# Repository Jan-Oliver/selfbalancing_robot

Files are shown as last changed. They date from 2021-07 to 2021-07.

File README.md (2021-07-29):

# selfbalancing_robot
Remote controlled self balancing robot. 

https://user-images.githubusercontent.com/49548379/127552782-20ae32ec-ad17-4d8e-8578-7c62c85af341.mp4

## The Robot

The robot consists of a fully 3D printed chassis, two Nema 17 Stepper Motors + motor drivers, a 6DOF-MPU6050 Inertial Measurement Unit and one transceiver module NRF24L01.  Using an Arduino Nano the IMU data is fused with the transmitted controls to drive the stepper motors accordingly. Furthermore a voltage divider is utilized to keep track of the LiPo voltage. The L7805 is used as a stepdown converter to power the Nano from the battery directly.

### Assembly
Robot_Schematics

## The Remote Controller

The RC uses a Joystick or another IMU to generate the controls for the selfbalancing robot. The controls are read by another Nano and send wirelessly using the second transceiver NRF24L01 module. 

### Assembly
Transmitter_Circuit_diagram_Breadboard

## Setting up the software
### Calibrate the IMUs
Especially the IMU used on the robot itself has to be calibrated nicely. Otherwise the robot will probably fall over. To calibrate your IMU it is suggested to put the robot on the table and run the provided calibration script. Open the Serial monitor and just wait for it to finish. The final values will show up eventually. Just copy them into the main script and you are ready to go. 

## RC robot in action

https://user-images.githubusercontent.com/49548379/127555006-d38b4bb5-38b9-4d4e-9c73-ccdcb0052809.mp4

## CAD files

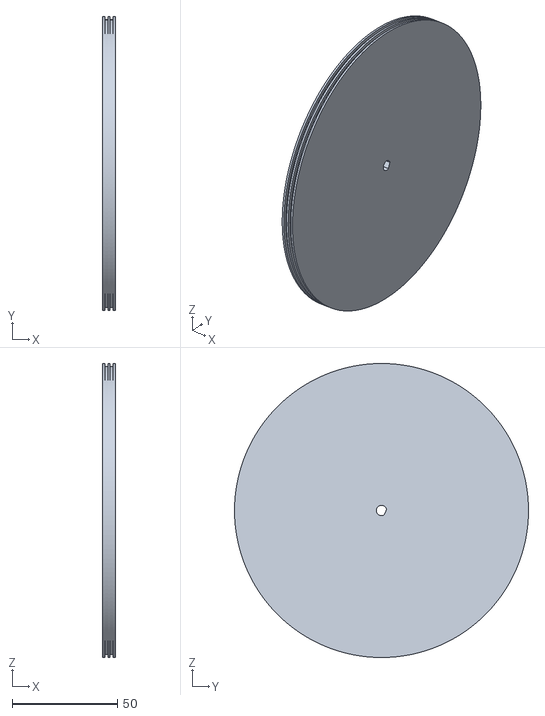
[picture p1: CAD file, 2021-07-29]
3D_printer_files/Rad Rechts.stl
6.00 x 140.0 x 140.0

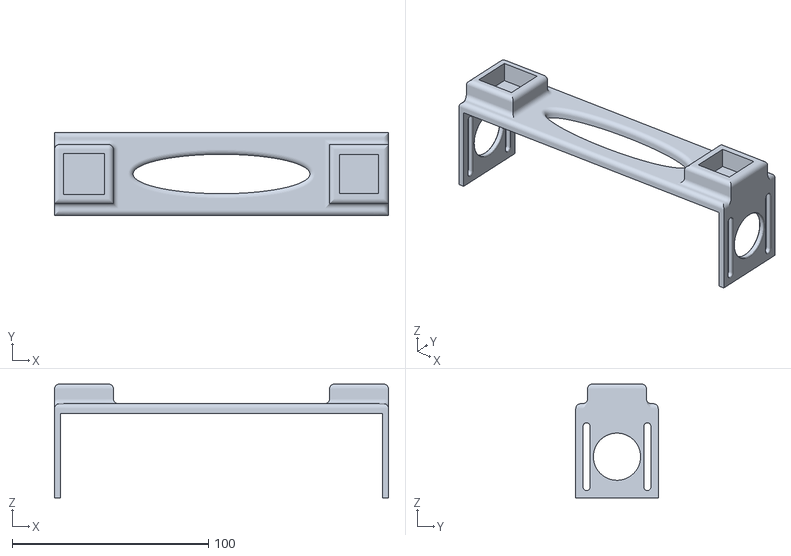
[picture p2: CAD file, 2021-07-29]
3D_printer_files/Motor-Connector.stl
170.0 x 42.0 x 58.0

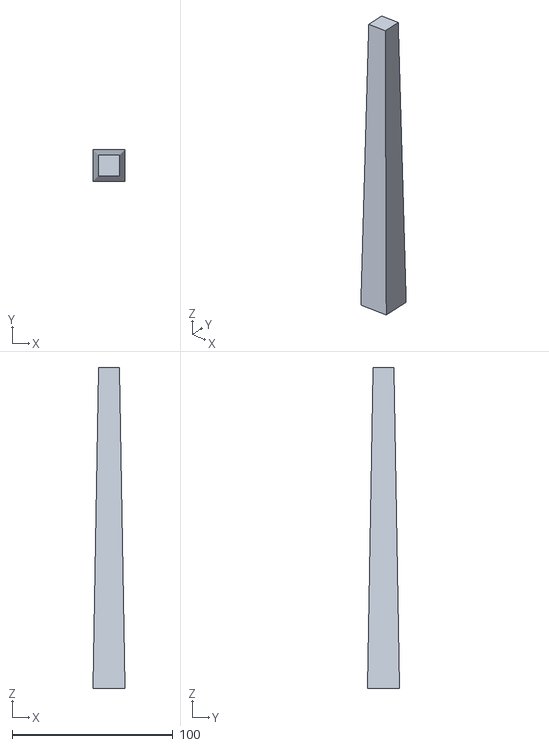
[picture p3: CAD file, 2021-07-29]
3D_printer_files/Träger Rechts.stl
20.0 x 20.0 x 200.0

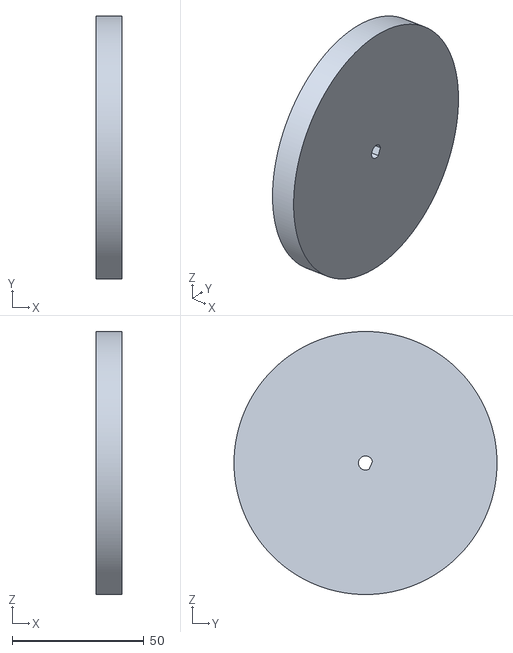
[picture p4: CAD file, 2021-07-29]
3D_printer_files/Rad Links Korrigierter Radius.stl
10.0 x 100.0 x 100.0

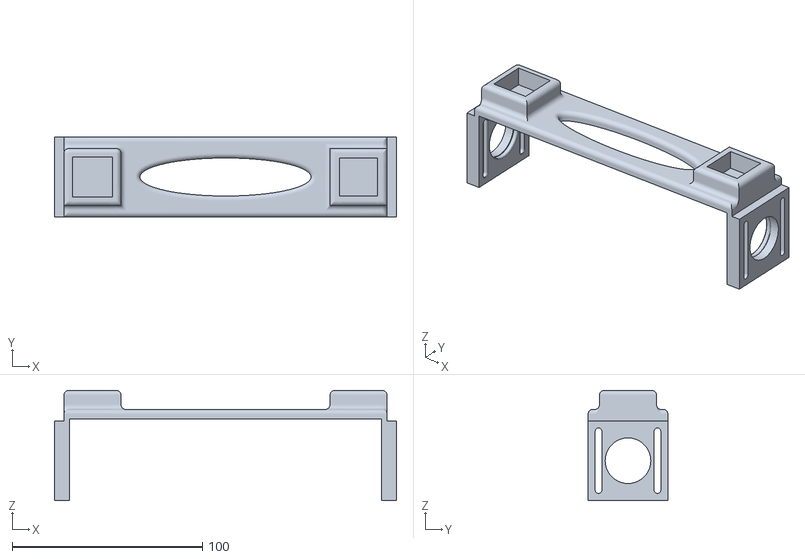
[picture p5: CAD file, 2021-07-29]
3D_printer_files/Motor-Connector_2.stl
180.0 x 42.0 x 58.0

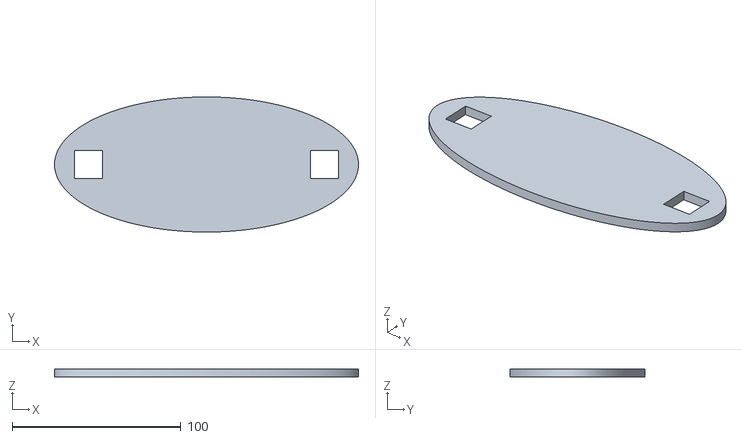
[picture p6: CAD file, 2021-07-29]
3D_printer_files/Ebene Unten.stl
180.0 x 80.0 x 5.00

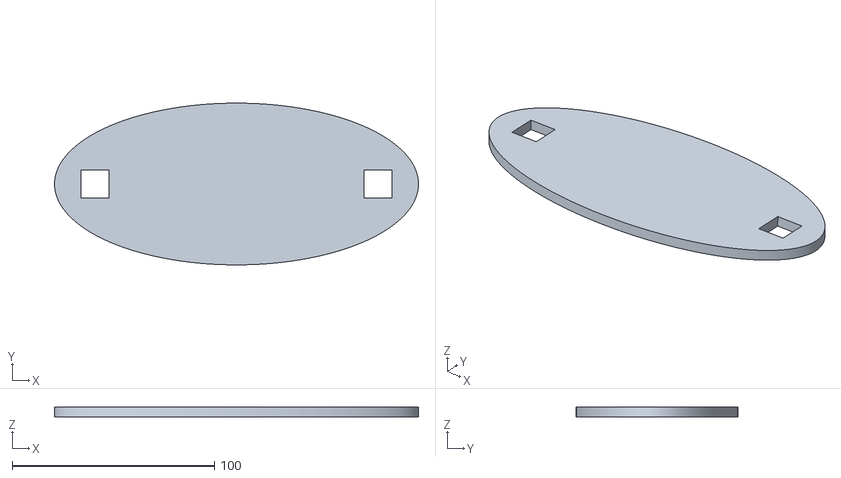
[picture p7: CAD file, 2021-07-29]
3D_printer_files/Ebene Oben.stl
180.0 x 80.0 x 5.00

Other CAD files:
3D_printer_files/Rad Links.stl
3D_printer_files/Träger Links.stl

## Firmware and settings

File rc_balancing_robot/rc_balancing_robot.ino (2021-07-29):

#include <Wire.h>
#include <math.h>
#define MPU_I2C 0b1101000

//NRF - RC Includes
#include <SPI.h>
#include <nRF24L01.h>
#include <RF24.h>


//#define DEBUG 
//Offsets for the IMU values
const float X_ACCEL_OFFSET = 890.21;
const float Y_ACCEL_OFFSET = 489.55;
const float Z_ACCEL_OFFSET = 45.49;
const float X_GYRO_OFFSET = -9.55;
const float Y_GYRO_OFFSET = 85.11;
const float Z_GYRO_OFFSET = 108.02;


//Constants which depend on the selected sensitivity of the IMU
const float ACCEL_SENSITIVITY_CONVERSION = 16384.0;
const float GYRO_SENSITIVITY_CONVERSION = 131.0;

//The Complementary filter needs a weight for the gyro data and the accel data to melt them
const float COMPL_FILTER_GYRO_WEIGHT = 0.9996;
struct AxisValues {
  float X;
  float Y;
  float Z;
}; 
//The raw data from the IMU
AxisValues accel_Raw;
AxisValues gyro_Raw;

//The values adapted to the current sensivity of the IMU
AxisValues accel;
AxisValues gyro;

//The estimated roll and pitch angles estimated by the accel data
float roll_Angle_Accel;
float pitch_Angle_Accel;
//The estimated roll and pitch angles estimated by the gyro data
float roll_Angle_Gyro;
float pitch_Angle_Gyro;

//To integrate the gyro-data you have to store the last timestempt to form a deltaTime
long oldTime;

//The estimated roll and pitch angel by the Complementary filter
float roll_Angle;
float pitch_Angle;

/**
 * Variables for PID
 */
float pid_P_Gain = 1.7;                                       //Gain setting for the P-controller 
float pid_I_Gain = 0.16;                                       //Gain setting for the I-controller 
float pid_D_Gain = 1;                                       //Gain setting for the D-controller 

float pid_Error,pitch_Error, pidI_Cum_Error, pidD_Last_Error, pid_Setpoint, pid_Output, self_balance_pid_setpoint;
float pid_Output_Left, pid_Output_Right;

/**
 * Variables for the motors
 */
const int right_Motor_Step = 7; 
const int right_Motor_Dir = 8; 
const int left_Motor_Step = 6; 
const int left_Motor_Dir = 5; 

int throttle_Counter_Motor_Right,throttle_Counter_Motor_Left,throttle_Motor_Memory_Right,throttle_Motor_Memory_Left;
int throttle_Motor_Left, throttle_Motor_Right;
/**
 * Variables for the voltage-measurement
 */
const int battery_Voltage_Measurement = A0;
const int BATTERY_VOLTAGE_NEW_VAL_WEIGHT = 0.05;
int battery_Voltage;
boolean batteryIsLow = false;

/**
 * RC Variables for NRF24L
 */
 //Variables to store the transmitted data
float pitchAngleNRF = 0.0;          //Raw pitch angle value which is received
float rollAngleNRF = 0.0;           //Raw roll angle value which is received

//Variables to setup NRF
const byte address[6] = "00001";
RF24 radio(9, 10); // CE, CSN
//Variable for control logic if no data is sent
int cyclesNoDataReceived = 0;
int maxSpeedMotors = 10;
void setup() {
  Serial.begin(9600);
  Wire.begin();

  //Set all Motor-Pins as Outputs
  pinMode(right_Motor_Dir,OUTPUT);
  pinMode(left_Motor_Dir,OUTPUT);
  pinMode(right_Motor_Step,OUTPUT);
  pinMode(left_Motor_Step,OUTPUT);

  //Measure the Battery Voltage
  pinMode(battery_Voltage_Measurement, INPUT);
  
  //To create a variable pulse for controlling the stepper motors a timer is created that will execute a piece of code (subroutine) every 20us
  //This subroutine is called TIMER2_COMPA_vect
  TCCR1A = 0;                                                               //Make sure that the TCCR1A register is set to zero initially
  TCCR1B = 0;                                                               //Make sure that the TCCR1B register is set to zero initially
  
  TCCR1B |= (1 << WGM12);                                                   //Set counter 1 to CTC (clear timer on compare) mode -> So you don't have to reset the timer in the ISR

  TCCR1B &= ~(1 << CS12);                                                   // 0 1 0 clkI/O/8 (prescaler) -> Set the 0
  TCCR1B |= (1 << CS11);                                                    // 0 1 0 clkI/O/8 (prescaler) -> Set the 1
  TCCR1B &= ~(1 << CS10);                                                   // 0 1 0 clkI/O/8 (prescaler) -> Set the 0

  TCNT1  = 0;                                                               //Set the initial timer value to 0
  OCR1A = 39;                                                               //Set the compare value to 39 -> 16MHz/[8(prescaler)*(1/20 * 10 ^-6)] - 1 = 39 
 
  TIMSK1 = (1 << OCIE1A);                                                   // Output Compare A Match Interrupt Enable

  sei();                                                                    //allow interrupts

  setupMPU();
  setupNRF();
}

void setupMPU() {
  Wire.beginTransmission(MPU_I2C); //This is the I2C address of the MPU (b1101000/b1101001 for AC0 low/high datasheet sec. 9.2)
  Wire.write(0x6B); //Accessing the register 6B - Power Management (Sec. 4.28)
  Wire.write(0b00000000); //Setting SLEEP register to 0. (Required; see Note on p. 9)
  Wire.endTransmission();  
  Wire.beginTransmission(MPU_I2C); //I2C address of the MPU
  Wire.write(0x1B); //Accessing the register 1B - Gyroscope Configuration (Sec. 4.4) 
  Wire.write(0x00000000); //Setting the gyro to full scale +/- 250deg./s 
  Wire.endTransmission(); 
  Wire.beginTransmission(MPU_I2C); //I2C address of the MPU
  Wire.write(0x1C); //Accessing the register 1C - Acccelerometer Configuration (Sec. 4.5) 
  Wire.write(0b00000000); //Setting the accel to +/- 2g
  Wire.endTransmission(); 
  //Set some filtering to improve the raw data.
  Wire.beginTransmission(MPU_I2C);                                     //Start communication with the address found during search
  Wire.write(0x1A);                                                         //We want to write to the CONFIG register (1A hex)
  Wire.write(0x03);                                                         //Set the register bits as 00000011 (Set Digital Low Pass Filter to ~43Hz)
  Wire.endTransmission();  
}

void setupNRF() {
  radio.begin();
  radio.openReadingPipe(0, address);
  radio.startListening();
}

void loop() {
  //Read NRF-Data if available
  if (radio.available()){                    //Wait for availabe data
    //Get and store the data
    int data[2] = {0};                      //If data is availabe create array with 5 slots to store data
    radio.read(&data, sizeof(data));        //Write the red data into the created array
    rollAngleNRF = -data[0];                //Store roll Angle and change the sign because of IMU positioning -> Move downwards should correspond to positive acceleration of the car
    pitchAngleNRF = data[1];                //Store pitch Angle
    cyclesNoDataReceived = 0; 
    #ifdef DEBUG
    Serial.print("NRF DATA-> Roll: ");
    Serial.print(rollAngleNRF);
    Serial.print("; Pitch: ");
    Serial.println(pitchAngleNRF);
    #endif          
  } else {
    cyclesNoDataReceived++;
  }

  if (cyclesNoDataReceived > 30) {
    pid_Setpoint = 0;
  }
  
  
  //Read Voltage
  battery_Voltage = (analogRead(battery_Voltage_Measurement) * 1.637) - 80;
  if(battery_Voltage < 1320 && battery_Voltage > 800) {
    batteryIsLow = true;
  }

  
  //Record Acceleration data
  Wire.beginTransmission(0b1101000); //I2C address of the MPU
  Wire.write(0x3B); //Starting register for Accel Readings
  Wire.endTransmission();
  Wire.requestFrom(0b1101000,6); //Request Accel Registers (3B - 40)
  while(Wire.available() < 6);
  accel_Raw.X = Wire.read()<<8|Wire.read(); //Store first two bytes into accelX
  accel_Raw.Y = Wire.read()<<8|Wire.read(); //Store middle two bytes into accelY
  accel_Raw.Z = Wire.read()<<8|Wire.read(); //Store last two bytes into accelZ

  //Record Gyro data
  Wire.beginTransmission(0b1101000); //I2C address of the MPU
  Wire.write(0x43); //Starting register for Gyro Readings
  Wire.endTransmission();
  Wire.requestFrom(0b1101000,6); //Request Gyro Registers (43 - 48)
  while(Wire.available() < 6);
  gyro_Raw.X = Wire.read()<<8|Wire.read(); //Store first two bytes into accelX
  gyro_Raw.Y = Wire.read()<<8|Wire.read(); //Store middle two bytes into accelY
  gyro_Raw.Z = Wire.read()<<8|Wire.read(); //Store last two bytes into accelZ

  //Apply the accelerometer offsets
  accel_Raw.X -= X_ACCEL_OFFSET;
  accel_Raw.Y -= Y_ACCEL_OFFSET;
  accel_Raw.Z -= Z_ACCEL_OFFSET;
  
  //Apply the gyroscope offsets
  gyro_Raw.X -= X_GYRO_OFFSET;
  gyro_Raw.Y -= Y_GYRO_OFFSET;
  gyro_Raw.Z -= Z_GYRO_OFFSET;

  //Convert raw accel data
  accel.X = accel_Raw.X / ACCEL_SENSITIVITY_CONVERSION ;
  accel.Y = accel_Raw.Y / ACCEL_SENSITIVITY_CONVERSION ; 
  accel.Z = accel_Raw.Z / ACCEL_SENSITIVITY_CONVERSION ;

  //Convert raw gyro data
  gyro.X = gyro_Raw.X / GYRO_SENSITIVITY_CONVERSION;
  gyro.Y = gyro_Raw.Y / GYRO_SENSITIVITY_CONVERSION; 
  gyro.Z = gyro_Raw.Z / GYRO_SENSITIVITY_CONVERSION;

  roll_Angle_Accel = atan2(accel_Raw.Y , accel_Raw.Z)/(2*M_PI)*360;
  pitch_Angle_Accel = atan2(-accel_Raw.X , sqrt((accel_Raw.Y*accel_Raw.Y)+(accel_Raw.Z*accel_Raw.Z)))/(2*M_PI)*360;
  
  long currentTime = millis();
  double dt = (currentTime - oldTime)/1000.0;
  //Calculate the estimated gyro angles
  roll_Angle_Gyro += gyro.X * dt;
  pitch_Angle_Gyro += gyro.Y * dt;

  //Estimated final compl. filter angles
  //roll_Angle = COMPL_FILTER_GYRO_WEIGHT * (roll_Angle + gyro.X * dt) + (1 - COMPL_FILTER_GYRO_WEIGHT) * roll_Angle_Accel;
  pitch_Angle = COMPL_FILTER_GYRO_WEIGHT * (pitch_Angle + gyro.Y * dt) + (1 - COMPL_FILTER_GYRO_WEIGHT) * pitch_Angle_Accel;

/**
 * PID-Controller:
 * pid_Error: Variable, which stores the Error between what the MPU measures and what the angle is supposed to be
 * pidI_Cum_Error: This is the integral which is done by adding all errors up
 * pidD_Last_Error: The Last Error is needed to calculate the differential of the pid-Controller
 * pid_Setpoint: The point we want to be stable at -> 0 degrees in our case
 * pid_Output: Final PID-Output value which has to be translated into a Motor speed and direction
 * float pid_P_Gain: Gain setting for the P-controller 
 * float pid_I_Gain: Gain setting for the I-controller 
 * float pid_D_Gain: Gain setting for the D-controller      
 */
 
  pid_Error = pitch_Angle - pid_Setpoint - self_balance_pid_setpoint;
  
  //if(pid_Output > 10 || pid_Output < -10)pid_Error += pid_Output * 0.015 ;

  pidI_Cum_Error += pid_I_Gain * pid_Error;

  if(pidI_Cum_Error > 400) {
    pidI_Cum_Error = 400;
  } else if (pidI_Cum_Error < -400) {
    pidI_Cum_Error = -400;
  }
  
  pid_Output = pid_P_Gain * pid_Error + pidI_Cum_Error + pid_D_Gain * (pid_Error - pidD_Last_Error);

  pidD_Last_Error = pid_Error;
  oldTime = currentTime;

  
  if(pid_Output < 5 && pid_Output > -5) {
    pid_Output = 0;
  }

  if(pid_Output > 400)pid_Output = 400;                                     //Limit the PID-controller to the maximum controller output: + and - 180!
  else if(pid_Output < -400)pid_Output = -400;

  
  if(pitch_Angle > 40 || pitch_Angle < -40 || batteryIsLow) {
     pid_Output = 0;
  }

  /**
   * Adapt the calculated output according to the rc-data:
   * Deadband between -4 and 4 degrees of transmitter.
   */
  pid_Output_Right = pid_Output;
  pid_Output_Left = pid_Output;

  if(rollAngleNRF >= 4) {
    pid_Output_Left += maxSpeedMotors;
    pid_Output_Right -= maxSpeedMotors;
  }

  if(rollAngleNRF < -4) {
    pid_Output_Left -= maxSpeedMotors;
    pid_Output_Right += maxSpeedMotors;
  }


  //Positive pitch angle -> Drive straight -> Lean foreward -> angle greater than 0 -> pid_Setpoint negative
  if (pitchAngleNRF >= 4) { 
    if(pid_Setpoint > -2.5) {
      pid_Setpoint -= 0.05;
    }
  }

  if(pitchAngleNRF < -4) {
    if(pid_Setpoint < 2.5) {
      pid_Setpoint += 0.05;
    }
  }

  if(pitchAngleNRF >= -4 && pitchAngleNRF < 4) {
    if(pid_Setpoint < 0) {
      pid_Setpoint += 0.05;
    } 
    if(pid_Setpoint > 0) {
      pid_Setpoint -= 0.05;
    }
  }

  
  //Allows the robot to adapt it's position to a neutral position in order to really get into a standstill.
  if(pid_Setpoint == 0){                                                    //If the setpoint is zero degrees
    if(pid_Output < 0) {
      self_balance_pid_setpoint += 0.0015;                  //Increase the self_balance_pid_setpoint if the robot is still moving forewards
    }
    if(pid_Output > 0) {
      self_balance_pid_setpoint -= 0.0015;                  //Decrease the self_balance_pid_setpoint if the robot is still moving backwards
    }
  }

  
  //Calculate the steps until which have to be taken untill the next motor pulse is allowed -> T = 1/(pid_Output * 20 * 10 ^-6) = 10 ^6 / (pid_Output * 20)  
  if(pid_Output_Right == 0) {
    throttle_Motor_Right = 0;
  } else {
    throttle_Motor_Right = 5000 / pid_Output_Right; 
  }

  if(pid_Output_Left == 0) {
    throttle_Motor_Left = 0;
  } else {
    throttle_Motor_Left = 5000 / pid_Output_Left; 
  }

  #ifdef DEBUG 
  Serial.print("PID_OUTPUT: ");
  Serial.print(pid_Output);
  Serial.print("-> Throttle_Right is therefore: ");
  Serial.print(throttle_Motor_Right);
  Serial.print("-> Throttle_Left is therefore: ");
  Serial.print(throttle_Motor_Left);
  Serial.print("->CUM Error ");
  Serial.print(pidI_Cum_Error);
  Serial.print("-> Pitch angle");
  Serial.print(pitch_Angle);
  Serial.print("Self balance");
  Serial.println(self_balance_pid_setpoint);
  #endif

}


///////////////////////////////////////////////////////////////////////////////////////////////////////////////////////////////////////
//Interrupt routine  TIMER2_COMPA_vect
///////////////////////////////////////////////////////////////////////////////////////////////////////////////////////////////////////
ISR(TIMER1_COMPA_vect){
  throttle_Counter_Motor_Right ++;
  if(throttle_Counter_Motor_Right > throttle_Motor_Memory_Right) {
    throttle_Counter_Motor_Right = 0;
    throttle_Motor_Memory_Right = throttle_Motor_Right;
    if(throttle_Motor_Memory_Right < 0) {                                         //Change spinning direction
      //PORTD &= ~(1 << PORTD5);
      PORTB &= ~(1 << PORTB0);
      throttle_Motor_Memory_Right *= -1;
    } else {                                                                //Change spinning direction
      //PORTD |= (1 << PORTD5);
      PORTB |= (1 << PORTB0);
    }
  } else if(throttle_Counter_Motor_Right == 1){
    PORTD |= 0b10000000;                                                     //(1 << PORTD7) | (1 << PORTD5);             
  }
  else if(throttle_Counter_Motor_Right == 2) {
    PORTD &= 0b01111111;                                                     //~(1 << PORTD7) & ~(1 << PORTD5);             
  }
  throttle_Counter_Motor_Left ++;
  if(throttle_Counter_Motor_Left > throttle_Motor_Memory_Left) {
    throttle_Counter_Motor_Left = 0;
    throttle_Motor_Memory_Left = throttle_Motor_Left;
    if(throttle_Motor_Memory_Left < 0) {                                         //Change spinning direction
      PORTD &= ~(1 << PORTD5);
      throttle_Motor_Memory_Left *= -1;
    } else {                                                                //Change spinning direction
      PORTD |= (1 << PORTD5);
    }
  } else if(throttle_Counter_Motor_Left == 1){
    PORTD |= 0b01000000;                                                     //(1 << PORTD7) | (1 << PORTD5);             
  }
  else if(throttle_Counter_Motor_Left == 2) {
    PORTD &= 0b10111111; 
  }
}

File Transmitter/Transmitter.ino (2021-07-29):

#include <SPI.h>
#include <nRF24L01.h>
#include <RF24.h>
#include <Wire.h>
#include <math.h>
#define MPU_I2C 0b1101000
/***************************************************
 * IMU Variables
 ***************************************************/
//Offsets for the IMU values
const float X_ACCEL_OFFSET = 312.58;
const float Y_ACCEL_OFFSET = -178.67;
const float Z_ACCEL_OFFSET = -157.19;
const float X_GYRO_OFFSET = -933.13;
const float Y_GYRO_OFFSET = -296.18;
const float Z_GYRO_OFFSET = -225.30;

//Constants which depend on the selected sensitivity of the IMU
const float ACCEL_SENSITIVITY_CONVERSION = 16384.0;
const float GYRO_SENSITIVITY_CONVERSION = 131.0;

//The Complementary filter needs a weight for the gyro data and the accel data to melt them
const float COMPL_FILTER_GYRO_WEIGHT = 0.95;

struct AxisValues {
  float X;
  float Y;
  float Z;
}; 
//The raw data from the IMU
AxisValues accel_Raw;
AxisValues gyro_Raw;

//The values adapted to the current sensivity of the IMU
AxisValues accel;
AxisValues gyro;

//The estimated roll and pitch angles estimated by the accel data
float roll_Angle_Accel;
float pitch_Angle_Accel;
//The estimated roll and pitch angles estimated by the gyro data
float roll_Angle_Gyro;
float pitch_Angle_Gyro;

//To integrate the gyro-data you have to store the last timestempt to form a deltaTime
long oldTime;

//The estimated roll and pitch angel by the Complementary filter
float roll_Angle;
float pitch_Angle;

/***************************************************
 * Joystick Variables
 ***************************************************/
//Joystick Variables
const int ctrlSW = 2;
const int ctrlX = A1;
const int ctrlY = A0;
const int ADC_RESOLUTION = 9;
//Joystick Variables to store the data
bool ctrlSWData = false;
int ctrlXData = 0;
int ctrlYData = 0;

//Transmitter object
RF24 radio(7, 8); // CE, CSN
//Adress for communication
const byte address[6] = "00001";

//Array of all the data which should be send
int data[5];

void setup() {
  Serial.begin(9600);
  radio.begin();
  radio.openWritingPipe(address);
  //radio.setPALevel(RF24_PA_MIN);
  radio.stopListening();
  pinMode(ctrlX,INPUT);
  pinMode(ctrlY,INPUT);
  pinMode(ctrlSW,INPUT);
  digitalWrite(ctrlSW,HIGH);
  //IMU-communication
  Wire.begin();
  setupMPU();
}

/**
 * Configure the MPU
 */
void setupMPU() {
  Wire.beginTransmission(MPU_I2C); //This is the I2C address of the MPU (b1101000/b1101001 for AC0 low/high datasheet sec. 9.2)
  Wire.write(0x6B); //Accessing the register 6B - Power Management (Sec. 4.28)
  Wire.write(0b00000000); //Setting SLEEP register to 0. (Required; see Note on p. 9)
  Wire.endTransmission();  
  Wire.beginTransmission(MPU_I2C); //I2C address of the MPU
  Wire.write(0x1B); //Accessing the register 1B - Gyroscope Configuration (Sec. 4.4) 
  Wire.write(0x00000000); //Setting the gyro to full scale +/- 250deg./s 
  Wire.endTransmission(); 
  Wire.beginTransmission(MPU_I2C); //I2C address of the MPU
  Wire.write(0x1C); //Accessing the register 1C - Acccelerometer Configuration (Sec. 4.5) 
  Wire.write(0b00000000); //Setting the accel to +/- 2g
  Wire.endTransmission(); 
}
/**
 * The main loop
 * First of all we read the Joystick Data which is pretty easy -> readJoystickData()
 * Afterwards it gets a bit more complicated. We have to first read the raw accel and gyro data from the Register -> recordAccelRegisters() and recordGyroRegisters()
 * Apply the needed offsets on this raw data to center it around 0 -> applyOffsets()
 * To get usefull data we have to convert the raw data with the corresponding selected sensitivity-values. -> convertFromRawData()
 * Now have to estimate the pitch and roll angles from the acceleration data. The yaw can't be obtained because the accel doesn't change along a rotation along the z-axis -> estimateAnglesAccel()
 * With these angles and the gyro data we can estimate the real angles by fusing both estimations. The accel data is bad at compensating vibrations, the gyro is drifting. By applying a
 * complementary filter we can get best of both worlds and obtain the final estimation -> complementaryFilter()
 * 
 * Pack all this data into one array called data (what a surprise :)) and send it to the driving car.
 * data[0] -> Joystick x-data: [0-1023]
 * data[1] -> Joystick y-data: [0-1023]
 * data[2] -> Joystick button data: 0 = pressed, 1 = not pressed
 * data[3] -> Estimated Roll-angle: Can be between -180 and 180 degrees but shouldn't come too close to that.
 * data[4] -> Estimated Pitch angle: Should be between -90 and 90 degrees and no more. Better not come close to -90 or +90
 */
void loop() {
  //Joystick
  readJoystickData();
  //IMU stuff
  recordAccelRegisters();
  recordGyroRegisters();
  applyOffsets();
  convertFromRawData();
  estimateAnglesAccel();
  complementaryFilter();
  
  data[0] = ctrlXData;
  data[1] = ctrlYData;
  data[2] = ctrlSWData;
  data[3] = roll_Angle;
  data[4] = pitch_Angle;
  radio.write(&data, sizeof(data));
  Serial.println(" sent data");
}

/***************************************************
 * Joystick Code
 ***************************************************/
void readJoystickData() {
  ctrlSWData = digitalRead(ctrlSW);
  ctrlXData = analogRead(ctrlX);
  ctrlYData = analogRead(ctrlY);
}

/***************************************************
 * IMU Code
 ***************************************************/
/**
 * Read raw accel data
 */
void recordAccelRegisters() {
  Wire.beginTransmission(0b1101000); //I2C address of the MPU
  Wire.write(0x3B); //Starting register for Accel Readings
  Wire.endTransmission();
  Wire.requestFrom(0b1101000,6); //Request Accel Registers (3B - 40)
  while(Wire.available() < 6);
  accel_Raw.X = Wire.read()<<8|Wire.read(); //Store first two bytes into accelX
  accel_Raw.Y = Wire.read()<<8|Wire.read(); //Store middle two bytes into accelY
  accel_Raw.Z = Wire.read()<<8|Wire.read(); //Store last two bytes into accelZ
}
/**
 * Read raw Gyro data
 */
void recordGyroRegisters() {
  Wire.beginTransmission(0b1101000); //I2C address of the MPU
  Wire.write(0x43); //Starting register for Gyro Readings
  Wire.endTransmission();
  Wire.requestFrom(0b1101000,6); //Request Gyro Registers (43 - 48)
  while(Wire.available() < 6);
  gyro_Raw.X = Wire.read()<<8|Wire.read(); //Store first two bytes into accelX
  gyro_Raw.Y = Wire.read()<<8|Wire.read(); //Store middle two bytes into accelY
  gyro_Raw.Z = Wire.read()<<8|Wire.read(); //Store last two bytes into accelZ
}
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

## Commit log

2021-07-29 Added th correct Receiver and Transmitter code
    [IMU_Transmitter.ino, rc_balancing_robot.ino]
2021-07-29 Added stl files for the 3D Printer
    [Ebene Oben.stl, Ebene Unten.stl, Motor-Connector.stl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]
2021-07-29 Added Offset Generator Script and renamed 3D Printer files folder
    [Ebene Oben.stl, Ebene Unten.stl, Motor-Connector.stl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]
